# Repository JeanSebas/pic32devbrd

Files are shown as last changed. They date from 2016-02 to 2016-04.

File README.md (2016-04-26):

# pic32devbrd

A general purpose development board for the PIC32MX250F128B microcontroller. Please see the [wiki] (https://github.com/irwineffect/pic32devbrd/wiki) for more information.

#Features:
* Onboard 3.3V switching regulator, designed to be powered off of the USB port
* PTC fuse to protect from short-circuit
* Onboard FTDI chip
* Power indication LED
* Tx/Rx LEDs
* General-purpose LED

---

Also, you should check out the [SUBLIBinal library](https://github.com/PalouseRobosub/SUBLIBinal), an efficient interrupt-driven library designed for boards using this microcontroller.

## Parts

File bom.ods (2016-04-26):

Type | Reference | Value | Footprint | Datasheet
C | C1 | 100n | Capacitors_SMD:C_0805_HandSoldering
C | C10 | 100n | Capacitors_SMD:C_0805_HandSoldering
C | C3 | 100n | Capacitors_SMD:C_0805_HandSoldering
C | C8 | 100n | Capacitors_SMD:C_0805_HandSoldering
C | C9 | 100n | Capacitors_SMD:C_0805_HandSoldering
C | C4 | 10u | Capacitors_SMD:C_0805_HandSoldering
C | C7 | 10u | Capacitors_SMD:C_0805_HandSoldering
C | C2 | 4.7u | Capacitors_SMD:C_0805_HandSoldering
C | C6 | 4.7u | Capacitors_SMD:C_0805_HandSoldering
C | C5 | 47p | Capacitors_SMD:C_0805_HandSoldering
C | C11 | 47p | Capacitors_SMD:C_0805_HandSoldering
Con | Con1 | prog_header | RS_footprints:Pin_Header_Staggered_1x06
D | D3 | PWR | LEDs:LED_0805
D | D4 | RB5 | LEDs:LED_0805
D | D2 | RX | LEDs:LED_0805
D | D1 | TX | LEDs:LED_0805
F | F1 | PTC Fuse | Capacitors_SMD:C_0805_HandSoldering
IC | IC1 | FT230X | Housings_SSOP:SSOP-16_3.9x4.9mm_Pitch0.635mm
IC | IC3 | LM3671 | TO_SOT_Packages_SMD:SOT-23-5
IC | IC2 | PIC32MX2xx/1xx | Housings_SSOP:SSOP-28_5.3x10.2mm_Pitch0.65mm
L | L1 | 2.2u | Capacitors_SMD:C_0805_HandSoldering
P | P2 | CONN_01X09 | Pin_Headers:Pin_Header_Straight_1x09
P | P3 | CONN_01X09 | Pin_Headers:Pin_Header_Straight_1x09
P | P1 | USB_OTG | RS_footprints:USB-MICRO-B
R | R5 | 10 | Resistors_SMD:R_0805_HandSoldering
R | R1 | 270 | Resistors_SMD:R_0805_HandSoldering
R | R2 | 270 | Resistors_SMD:R_0805_HandSoldering
R | R6 | 270 | Resistors_SMD:R_0805_HandSoldering
R | R7 | 270 | Resistors_SMD:R_0805_HandSoldering
R | R3 | 10k | Resistors_SMD:R_0805_HandSoldering
R | R4 | 1k | Resistors_SMD:R_0805_HandSoldering
R | R8 | 27 | Resistors_SMD:R_0805_HandSoldering
R | R9 | 27 | Resistors_SMD:R_0805_HandSoldering

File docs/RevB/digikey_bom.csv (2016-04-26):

Index | Quantity | Part Number | Manufacturer Part Number | Description | Customer Reference | Backorder | Unit Price | Extended Price
1 | 12 | 311-270CRCT-ND | RC0805FR-07270RL | RES SMD 270 OHM 1% 1/8W 0805 | RESISTOR 270 OHM | 0 | 0.02100 | $0.25
2 | 15 | 1276-1007-1-ND | CL21F104ZBCNNNC | CAP CER 0.1UF 50V Y5V 0805 | CAPACITOR 100 NF | 0 | 0.03100 | $0.47
3 | 3 | 311-10.0KCRCT-ND | RC0805FR-0710KL | RES SMD 10K OHM 1% 1/8W 0805 | RESISTOR 10 KOHM | 0 | 0.10000 | $0.30
4 | 3 | 311-1.00KCRCT-ND | RC0805FR-071KL | RES SMD 1K OHM 1% 1/8W 0805 | RESISTOR 1 KOHM | 0 | 0.10000 | $0.30
5 | 6 | 311-1371-1-ND | CC0805ZRY5V6BB475 | CAP CER 4.7UF 10V Y5V 0805 | CAPACITOR 4.7 UF | 0 | 0.10000 | $0.60
6 | 3 | LM3671MF-3.3/NOPBCT-ND | LM3671MF-3.3/NOPB | IC REG BUCK 3.3V 0.6A SYNC SOT23 | 3.3V REGULATOR | 0 | 0.92000 | $2.76
7 | 3 | 445-8658-1-ND | MLZ2012M2R2HT000 | FIXED IND 2.2UH 600MA 160 MOHM | INDUCTOR 2.2 UH | 0 | 0.15000 | $0.45
8 | 3 | 311-10.0CRCT-ND | RC0805FR-0710RL | RES SMD 10 OHM 1% 1/8W 0805 | RESISTOR 10 OHM | 0 | 0.10000 | $0.30
9 | 6 | 311-1355-1-ND | CC0805ZKY5V6BB106 | CAP CER 10UF 10V Y5V 0805 | CAPACITOR 10 UF | 0 | 0.17000 | $1.02
10 | 3 | 768-1154-5-ND | FT230XS-U | IC USB SERIAL BASIC UART 16SSOP | FTDI CHIP | 0 | 2.04000 | $6.12
11 | 3 | 507-1811-1-ND | 0ZCK0020FF2G | PTC RESTTBLE 0.20A 9V CHIP 0805 | PTC FUSE | 0 | 0.15000 | $0.45
12 | 3 | 160-1423-1-ND | LTST-C171GKT | LED GREEN CLEAR 0805 SMD | LED GREEN | 0 | 0.28000 | $0.84
13 | 3 | 160-1427-1-ND | LTST-C171KRKT | LED RED CLEAR 0805 SMD | LED RED | 0 | 0.30000 | $0.90
14 | 3 | 160-1428-1-ND | LTST-C171KSKT | LED YELLOW CLEAR 0805 SMD | LED YELLOW | 0 | 0.32000 | $0.96
15 | 3 | 160-1579-1-ND | LTST-C170TBKT | LED BLUE CLEAR 0805 SMD | LED BLUE | 0 | 0.44000 | $1.32
16 | 3 | 609-4618-1-ND | 10118194-0001LF | CONN USB MICRO B RECPT SMT R/A | USB MICRO B | 0 | 0.46000 | $1.38
17 | 3 | S1011EC-25-ND | PRPC025SAAN-RC | CONN HEADER .100" SNGL STR 25POS |  | 0 | 0.55000 | $1.65
18 | 6 | 311-27ARCT-ND | RC0805JR-0727RL | RES SMD 27 OHM 5% 1/8W 0805 | RESISTOR 27 OHM | 0 | 0.10000 | $0.60
19 | 6 | 1276-1156-1-ND | CL21C470JBANNNC | CAP CER 47PF 50V NP0 0805 | CAPACITOR 47 PF | 0 | 0.10000 | $0.60
 |  |  |  |  |  |  | Subtotal | $21.27

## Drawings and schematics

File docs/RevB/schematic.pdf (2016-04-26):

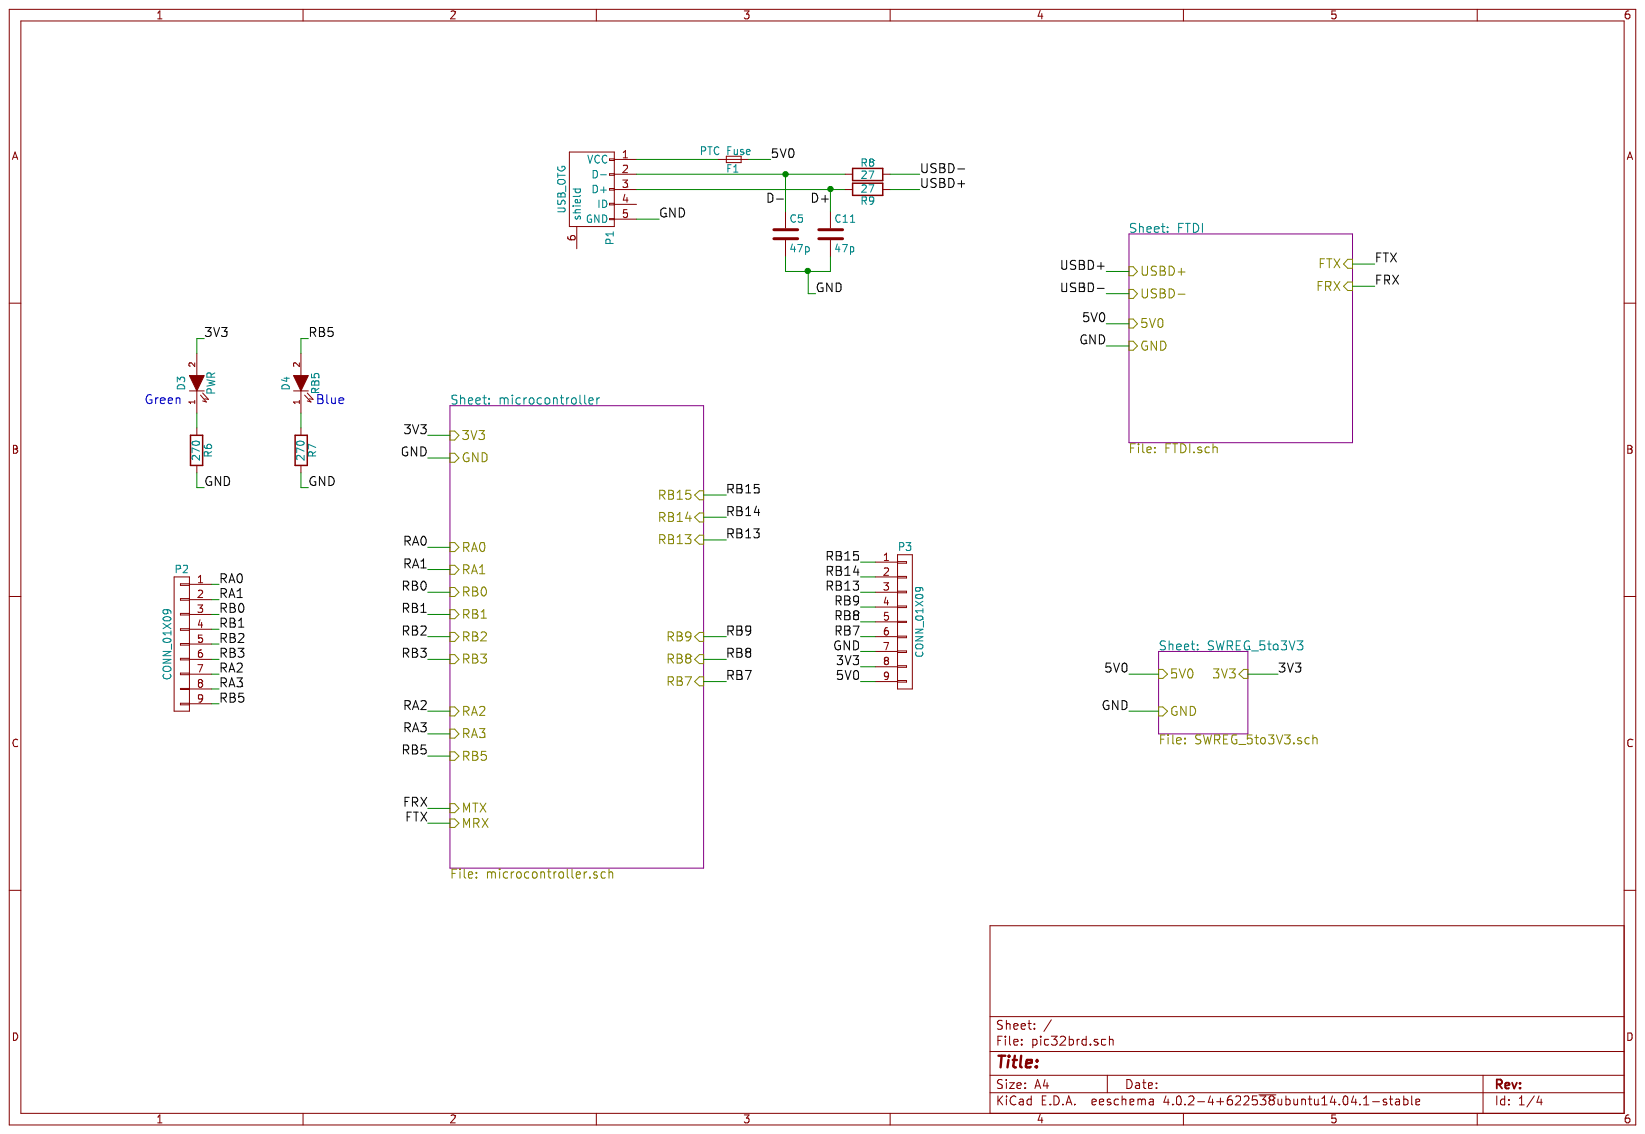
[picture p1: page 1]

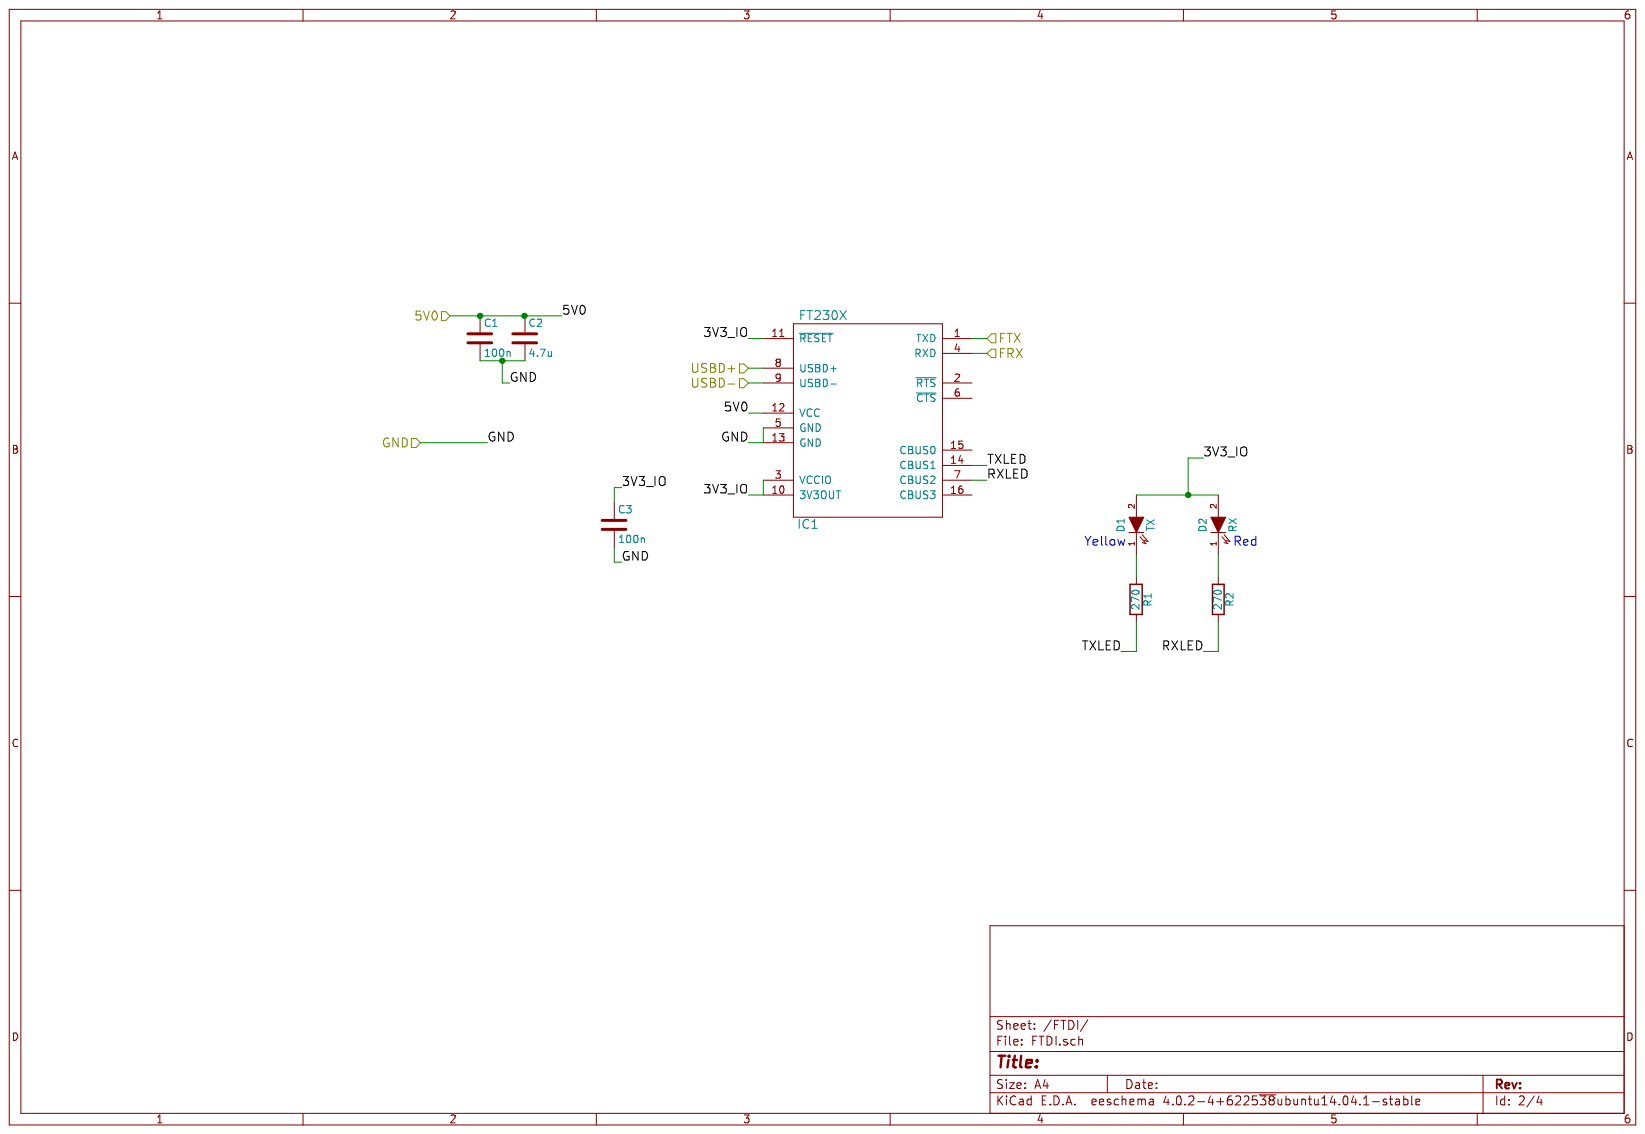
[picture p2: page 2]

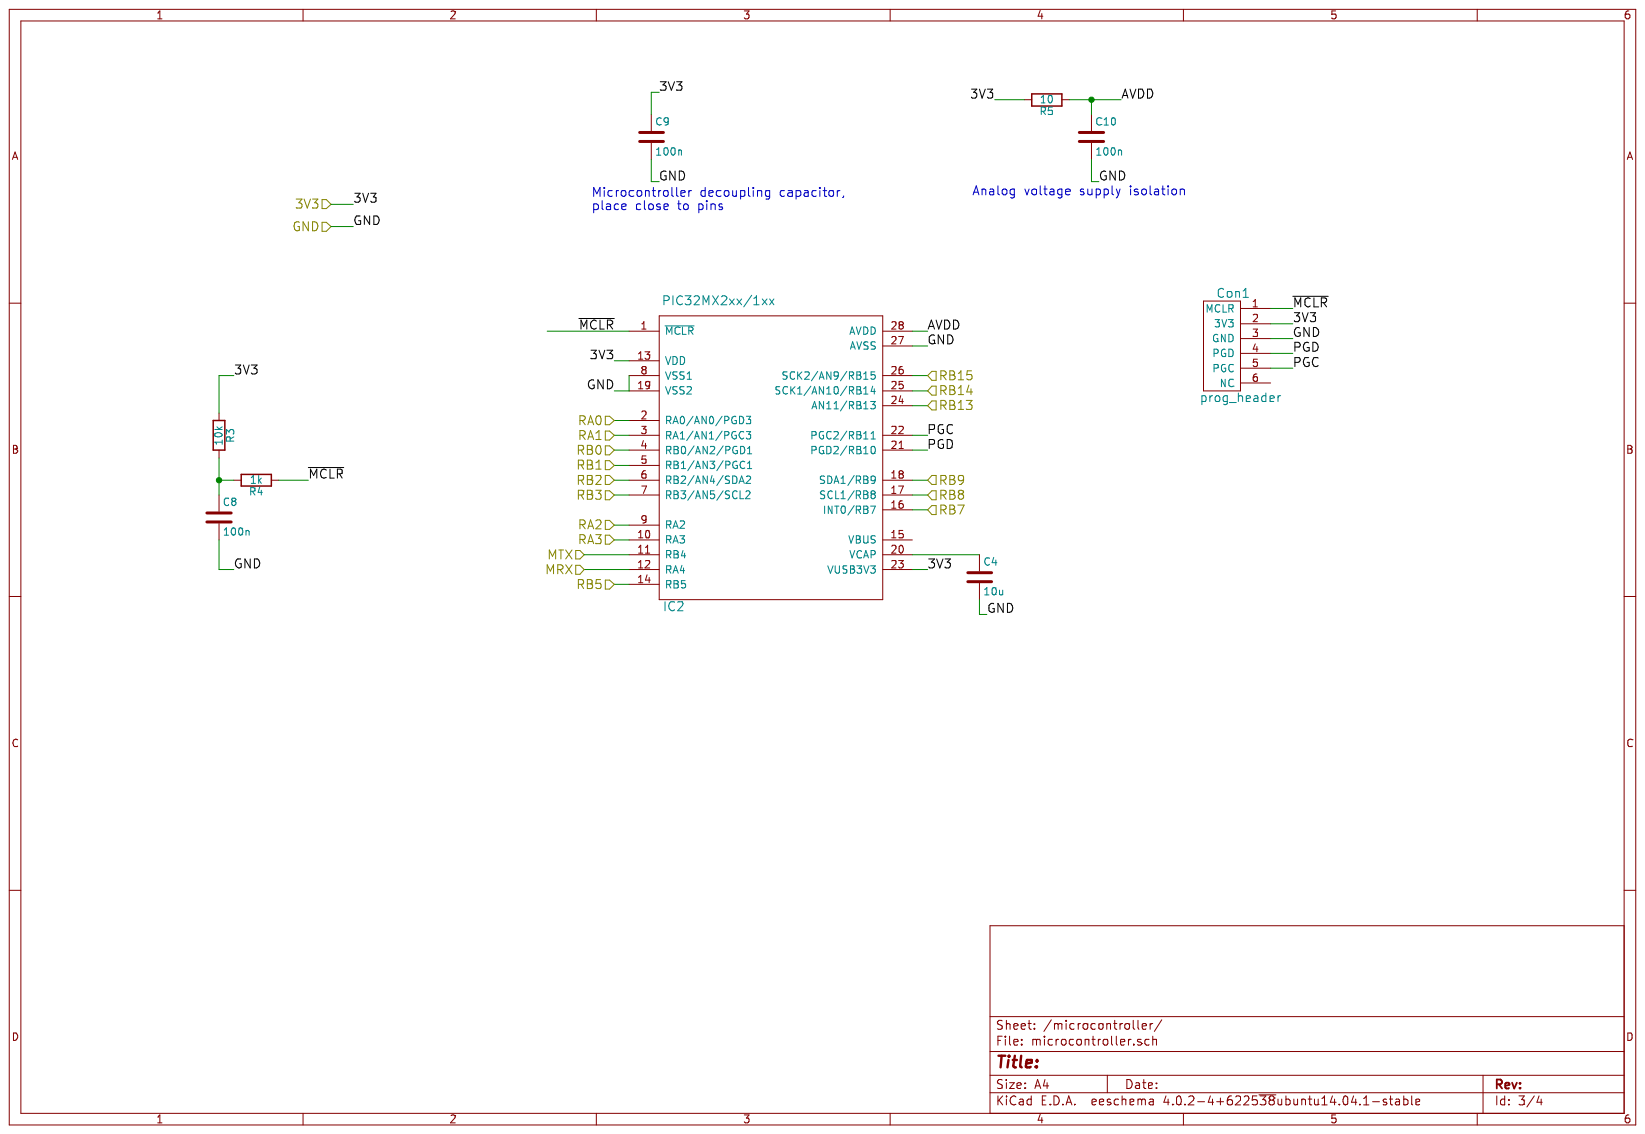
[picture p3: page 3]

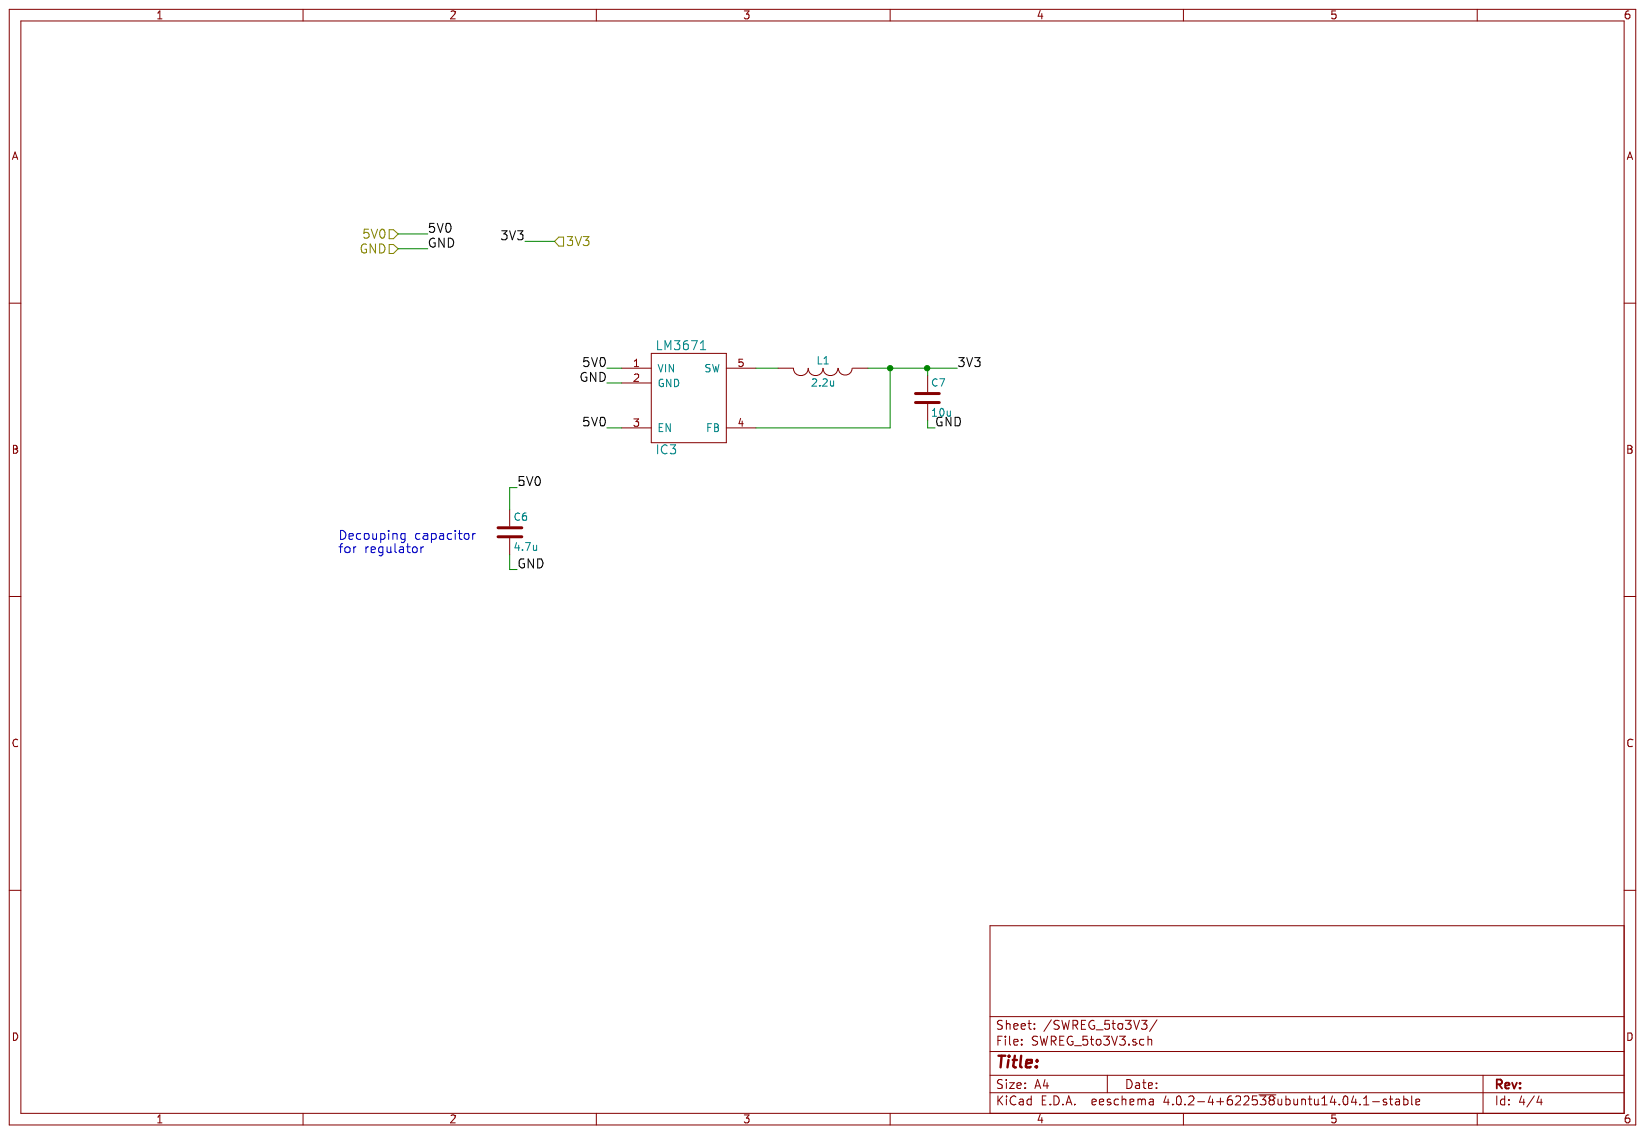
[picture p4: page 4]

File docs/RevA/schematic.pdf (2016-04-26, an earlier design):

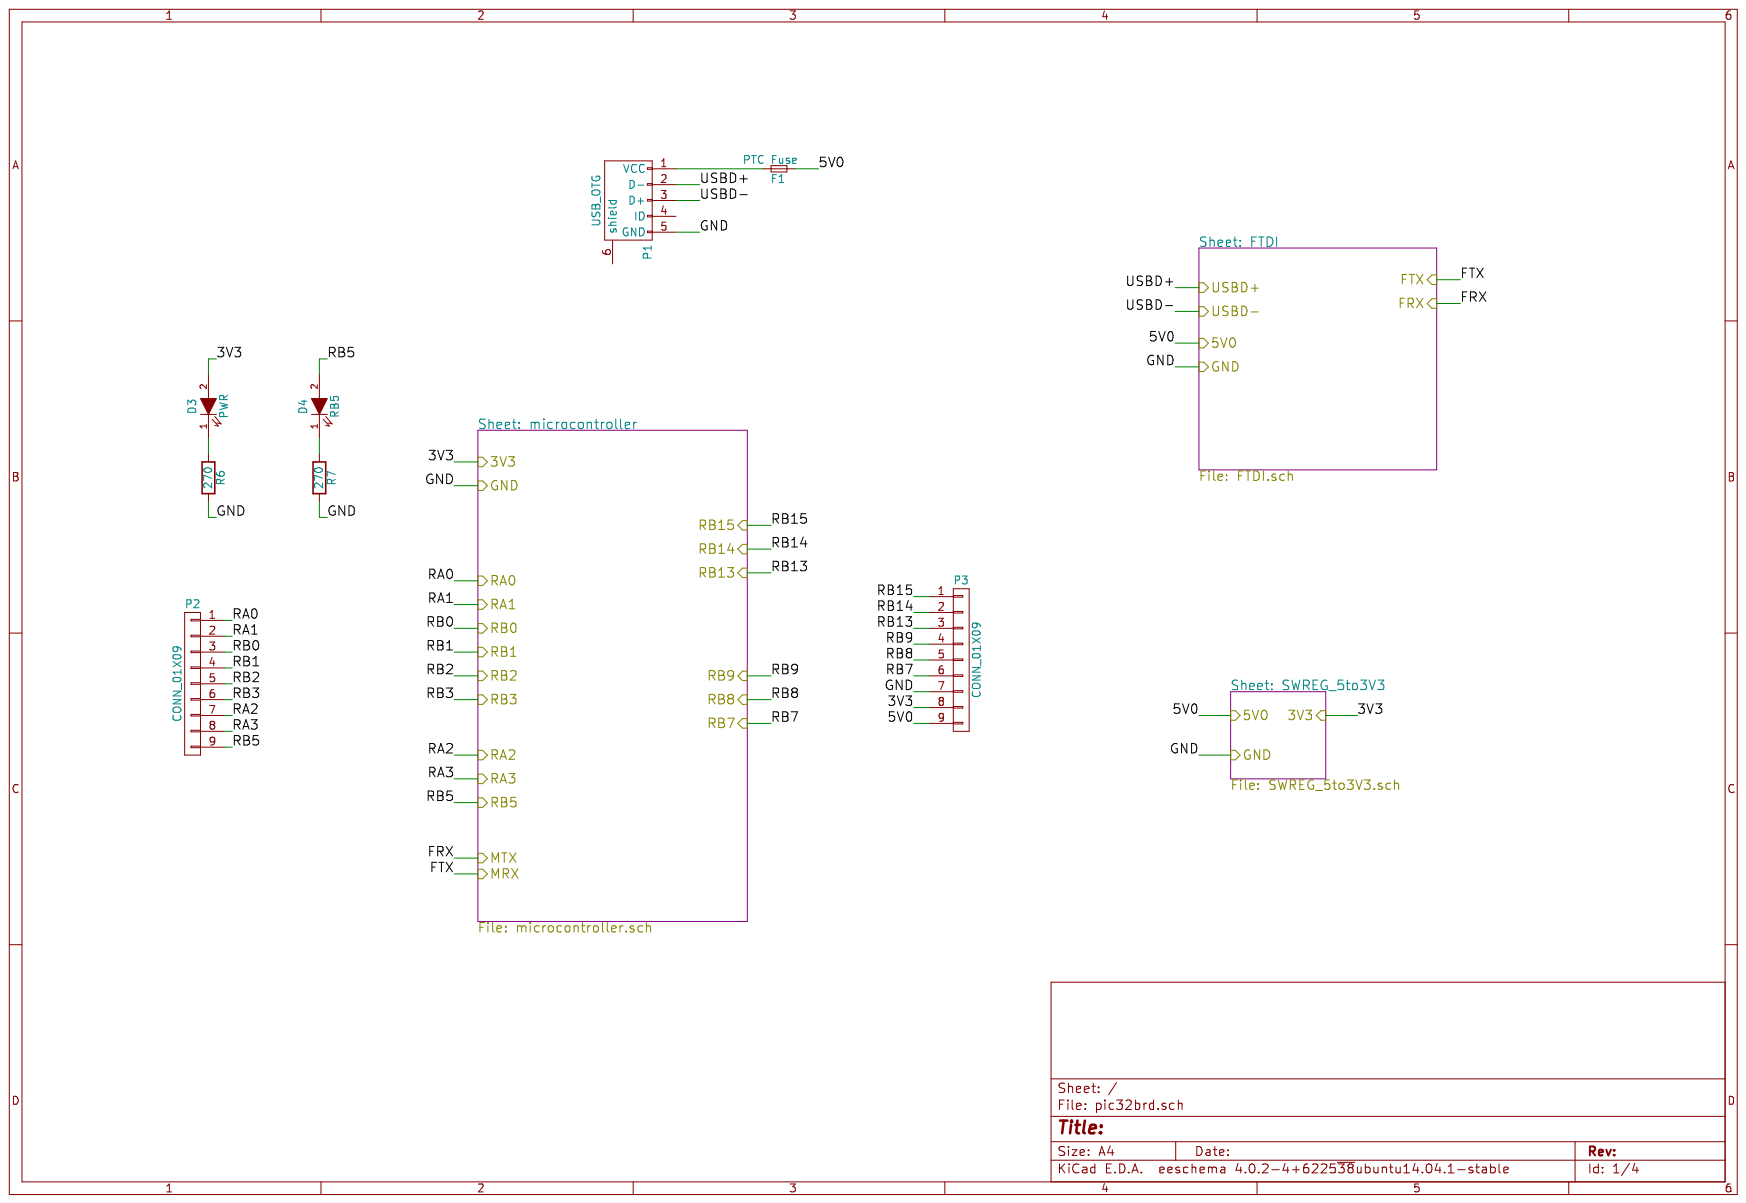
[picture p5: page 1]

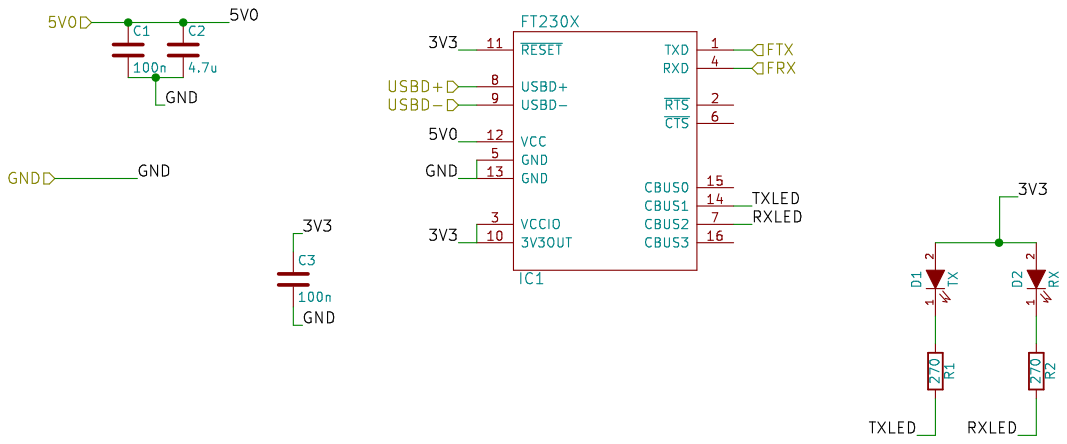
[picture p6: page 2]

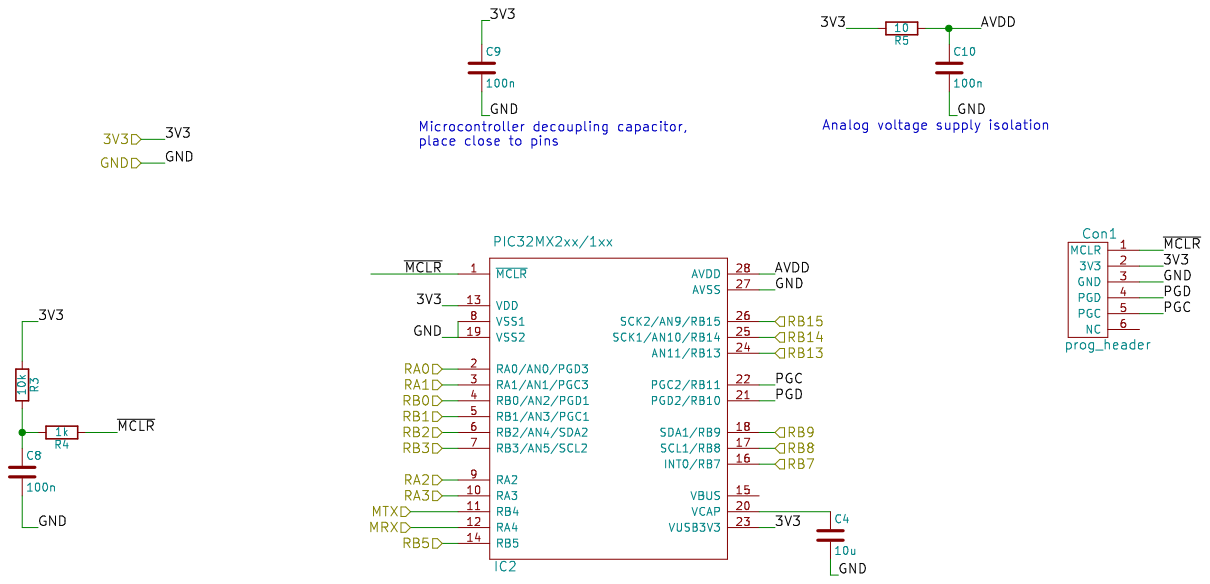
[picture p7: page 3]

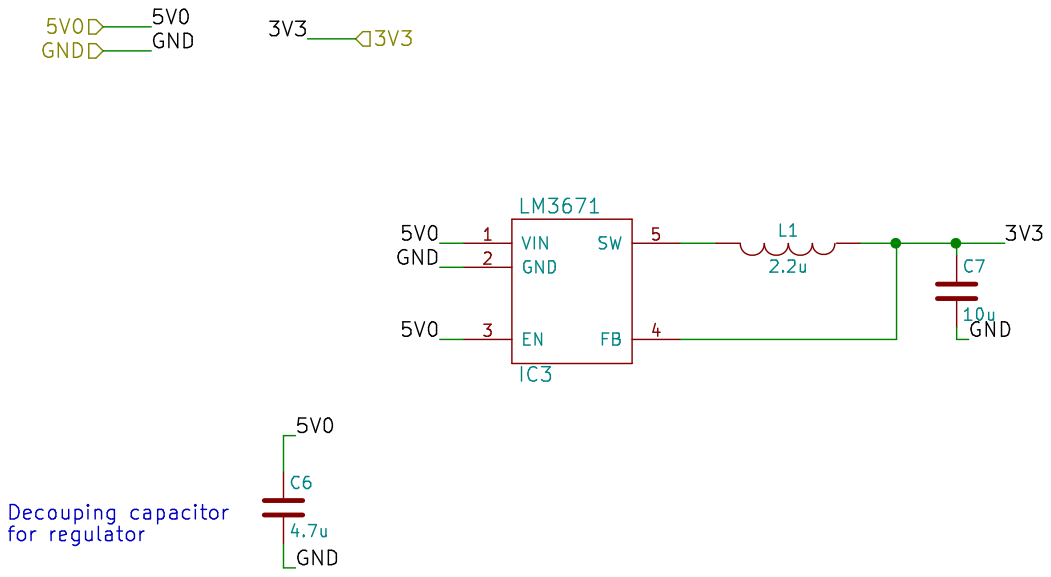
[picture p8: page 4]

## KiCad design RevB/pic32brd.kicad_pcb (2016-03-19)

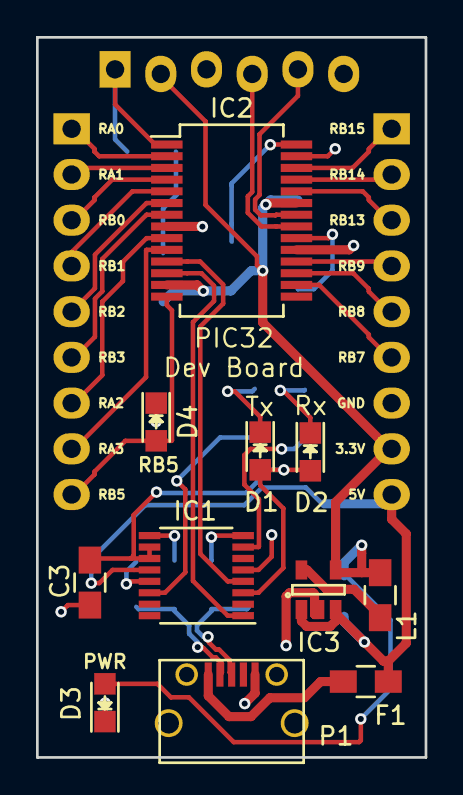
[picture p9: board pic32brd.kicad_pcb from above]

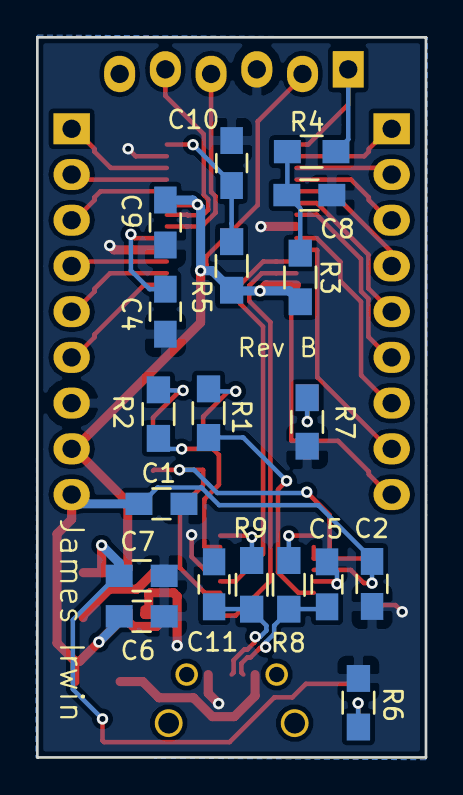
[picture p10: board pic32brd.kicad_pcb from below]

Board: 2 copper layers, 21.6 x 40.0 mm, 33 parts (19 on the bottom side), 39 nets.

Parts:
C1, C3, C8, C9, C10: 100n; C_0805_HandSoldering
C2, C6: 4.7u; C_0805_HandSoldering
C4, C7: 10u; C_0805_HandSoldering
C5, C11: 47p; C_0805_HandSoldering
Con1: prog_header; Pin_Header_Staggered_1x06
D1: TX; LED_0805
D2: RX; LED_0805
D3: PWR; LED_0805
D4: RB5; LED_0805
F1: PTC Fuse; C_0805_HandSoldering
IC1: FT230X; SSOP-16_3.9x4.9mm_Pitch0.635mm
IC2: PIC32MX2xx/1xx; SSOP-28_5.3x10.2mm_Pitch0.65mm
IC3: LM3671; SOT-23-5
L1: 2.2u; C_0805_HandSoldering
P1: USB_OTG; USB-MICRO-B
P2, P3: CONN_01X09; Pin_Header_Straight_1x09
R1, R2, R6, R7: 270; R_0805_HandSoldering
R3: 10k; R_0805_HandSoldering
R4: 1k; R_0805_HandSoldering
R5: 10; R_0805_HandSoldering
R8, R9: 27; R_0805_HandSoldering

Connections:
/D+: C11.1, P1.3, R9.2
/D-: C5.1, P1.2, R8.1
/FTDI/3V3_IO: C3.1, D1.2, D2.2, IC1.3, IC1.10, IC1.11
/FTDI/5V0: C1.1, C2.1, C6.1, F1.1, IC1.12, IC3.1, IC3.3, P3.9
/FTDI/FRX: IC1.4, IC2.11
/FTDI/FTX: IC1.1, IC2.12
/FTDI/GND: C1.2, C2.2, C3.2, C4.2, C5.2, C6.2, C7.2, C8.2, C9.2, C10.2, C11.2, Con1.3, IC1.5, IC1.13, IC2.8, IC2.19, IC2.27, IC3.2, P1.5, P3.7, R6.2, R7.2
/FTDI/RXLED: IC1.7, R2.2
/FTDI/TXLED: IC1.14, R1.2
/FTDI/USBD+: IC1.8, R9.1
/FTDI/USBD-: IC1.9, R8.2
/SWREG_5to3V3/3V3: C7.1, C9.1, Con1.2, D3.2, IC2.13, IC2.23, IC3.4, L1.1, P3.8, R3.1, R5.2
/microcontroller/AVDD: C10.1, IC2.28, R5.1
/microcontroller/PGC: Con1.5, IC2.22
/microcontroller/PGD: Con1.4, IC2.21
/microcontroller/RA0: IC2.2, P2.1
/microcontroller/RA1: IC2.3, P2.2
/microcontroller/RA2: IC2.9, P2.7
/microcontroller/RA3: IC2.10, P2.8
/microcontroller/RB0: IC2.4, P2.3
/microcontroller/RB1: IC2.5, P2.4
/microcontroller/RB2: IC2.6, P2.5
/microcontroller/RB3: IC2.7, P2.6
/microcontroller/RB5: D4.2, IC2.14, P2.9
/microcontroller/RB7: IC2.16, P3.6
/microcontroller/RB8: IC2.17, P3.5
/microcontroller/RB9: IC2.18, P3.4
/microcontroller/RB13: IC2.24, P3.3
/microcontroller/RB14: IC2.25, P3.2
/microcontroller/RB15: IC2.26, P3.1
/microcontroller/~MCLR: Con1.1, IC2.1, R4.1
unnamed: C4.1, IC2.20
unnamed: C8.1, R3.2, R4.2
unnamed: D1.1, R1.1
unnamed: D2.1, R2.1
unnamed: D3.1, R6.1
unnamed: D4.1, R7.1
unnamed: F1.2, P1.1
unnamed: IC3.5, L1.2

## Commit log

2015-12-03 added initial files
    might need to add library files, idk
    [FTDI.sch, SWREG_5to3V3.sch, microcontroller.sch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]
2016-02-20 rev A
    [FTDI.sch, SWREG_5to3V3.sch, microcontroller.sch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]
2016-03-13 finished revA backup
    [FTDI.sch, SWREG_5to3V3.sch, bom.ods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]
2016-03-19 Rev B
    added USB termination, swapped D+ and D- lines to be correct, and re-routed the board
    [FTDI.sch, SWREG_5to3V3.sch, microcontroller.sch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]
2016-04-02 copied revB files to own folder
    [FTDI.sch, SWREG_5to3V3.sch, bom.ods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]
2016-04-02 swapped Tx and Rx silkscreen labels also moved LED labels on schematic so Rx is still red and Tx is yellow the bug was that LED labeling was from FTDI chip's perspective, not the microcontroller's pe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
    [FTDI.sch, pic32brd.kicad_pcb]
2016-04-26 updated bom for revB
    [bom.ods]
2016-04-26 added schematics for boards
2016-04-26 added digikey bom for boards
    [digikey_bom.csv]
